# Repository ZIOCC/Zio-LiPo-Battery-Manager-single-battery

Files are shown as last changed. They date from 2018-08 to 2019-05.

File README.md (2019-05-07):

# Zio LiPo Battery Manager (Single battery)

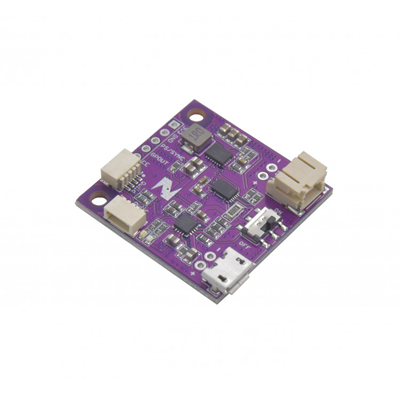
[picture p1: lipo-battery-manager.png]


> This product can be available for purchase [here](https://www.smart-prototyping.com/Zio-LiPo-Battery-Manager.html).

#### Description

This board combines a lithium polymer battery charger, fuel gauge, and voltage regulator, all in one neat little PCB. It also features a miniature DPDT power switch so that you can easily turn your project on and off without disconnecting the battery.

The Battery Manager’s TI BQ27441-G1A I2C Fuel Gauge is a Coulomb-counter, tracking the amount of power that has been discharged since your battery was fully charged. The amount of power remaining is calculated based on the capacity of that battery that you’ve set via the [Sparkfun BQ27441-G1 I2C library](https://learn.sparkfun.com/tutorials/battery-babysitter-hookup-guide#bq27441-arduino-library). Using the library, you can also read the raw voltage of your LiPo battery’s output. And because this is a Qwiic device, your MCU can check this information even if your battery and Battery Manager board are all the way at the other end of your daisy-chain of Qwiic modules. And if your Power Module is close to your MCU, just connect the GPOUT interrupt pin to one of your MCU’s GPIO pins to get a heads-up when the tank is running low. And because of the built-in current-sensing resistor circuit, you can even measure your project’s real-time current consumption.

The Battery Manager’s BQ24075 battery charger IC can charge your single-cell lithium-ion battery pack at up to 1.5A.

Our Battery Manager board is based on [Sparkfun’s Battery Babysitter](https://www.sparkfun.com/products/13777), and while the pin-out isn’t exactly the same, their [Hookup Guide](https://learn.sparkfun.com/tutorials/battery-babysitter-hookup-guide) is a great resource for getting started with our board as well.

Note: This board requires the use of the Qwiic (4-pin JST-SH) connector for accessing the I2C functionality of the BQ27441-G1A. If you intend to use this board in a project where your MCU doesn’t include a Qwiic connector, make sure you pick up a [Qwiic-to-breadboard cable](https://www.smart-prototyping.com/Prototyping-Modules/zio/Qwiic-to-Breadboard-Male-Header-150mm-Cable-2.54mm-10pcs), or any [Qwiic cable](https://www.smart-prototyping.com/index.php?route=product/search&search=qwiic%20cable) and a [Qwiic adapter board](https://www.smart-prototyping.com/Prototyping-Modules/zio/Zio-Qwiic-Adapter.html).

##### Features

* Protects the battery from running outside the safe operating area.
* Easy to connect to any ZIO products with one simple Qwiic cable.
* Features a dynamic power-path management which will maintain a solid output supply of 3.3V
* Contains a safety timer which will turn off the charger after 6.25 hours.

#### Specification

* Input Voltage- 6V max
* Output Voltage- 3.3V
* Output current- 1.5A max
* Qwiic connectors 3.3v and 1.5A max
* Battery Connector: PH Connector
* Battery Charger IC: BQ24075
* Power Manager IC: TPS63020DSJR
* Battery Gauge IC: BQ27441-G1
* I2C address:0x55
* Dimensions: 32.23x 33.24 mm
* Weight: 4.9g

#### Links

* [Eagle files](https://github.com/ZIOCC/Zio-LiPo-Battery-Manager-single-battery/tree/master/EAGLE)

> ###### About Zio
> Zio is a new line of open sourced, compact, and grid layout boards, fully integrated for Arduino and Qwiic ecosystem. Designed ideally for wearables, robotics, small-space limitations or other on the go projects. Check out other awesome Zio products [here](https://www.smart-prototyping.com/Zio).

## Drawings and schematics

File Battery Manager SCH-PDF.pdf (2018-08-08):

# GND 10k 1%

A

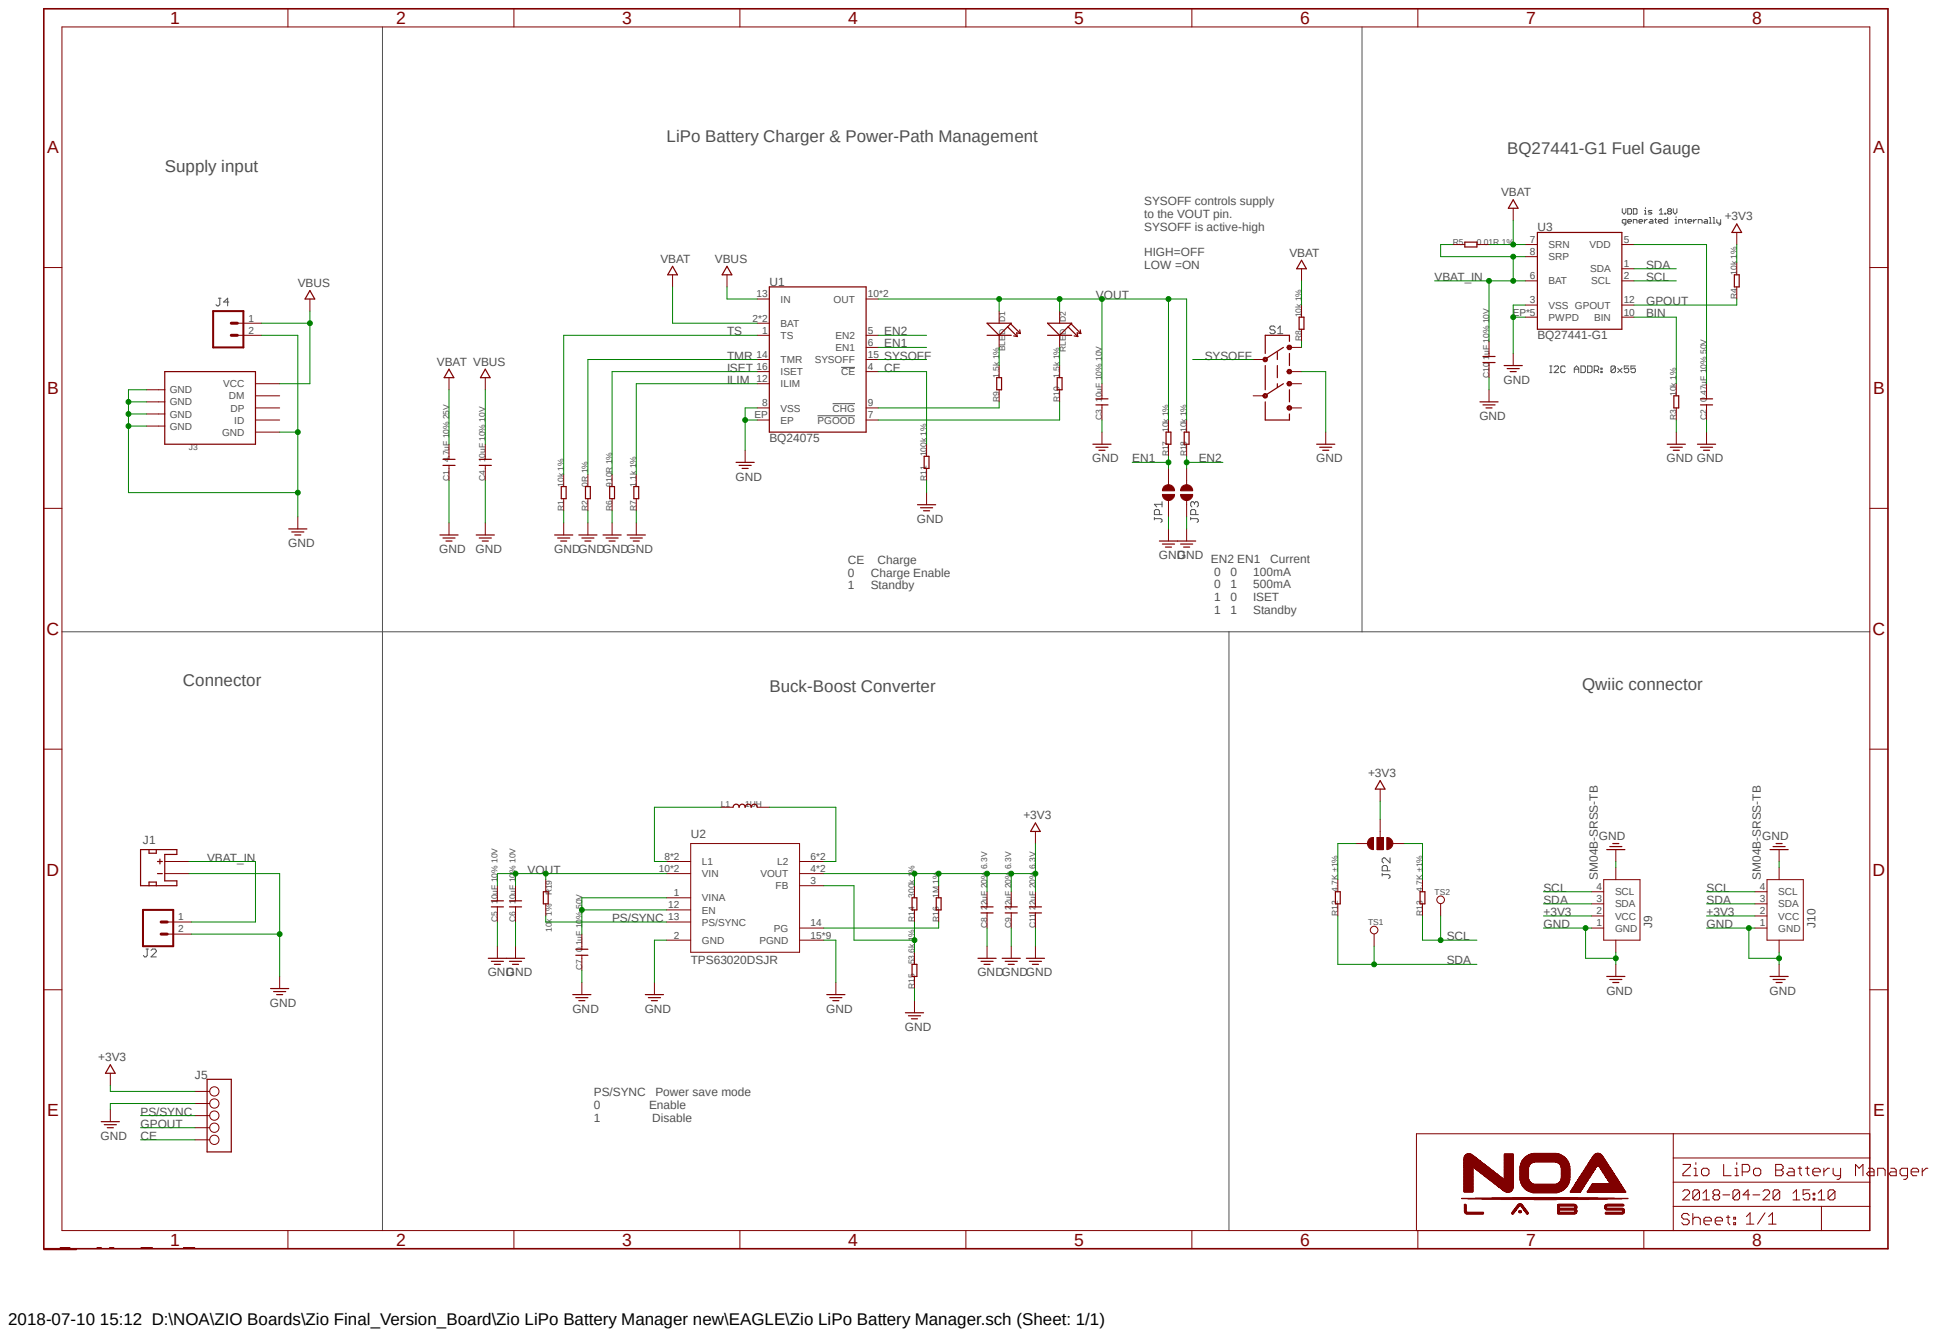
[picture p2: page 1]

Supply input | SYSOFF controls supply SYSOFF is active-high HIGH=OFF VBAT VBAT VBUS LOW =ON | BQ27441-G1 Fuel Gauge LiPo Battery Charger & Power-Path Management VBAT

to the VOUT pin.

VCC GND GND GND GND

PS/SYNC Power save mode
0 Enable
1 Disable

2018-07-10 15:12 D:\NOA\ZIO Boards\Zio Final_Version_Board\Zio LiPo Battery Manager new\EAGLE\Zio LiPo Battery Manager.sch (Sheet: 1/1)

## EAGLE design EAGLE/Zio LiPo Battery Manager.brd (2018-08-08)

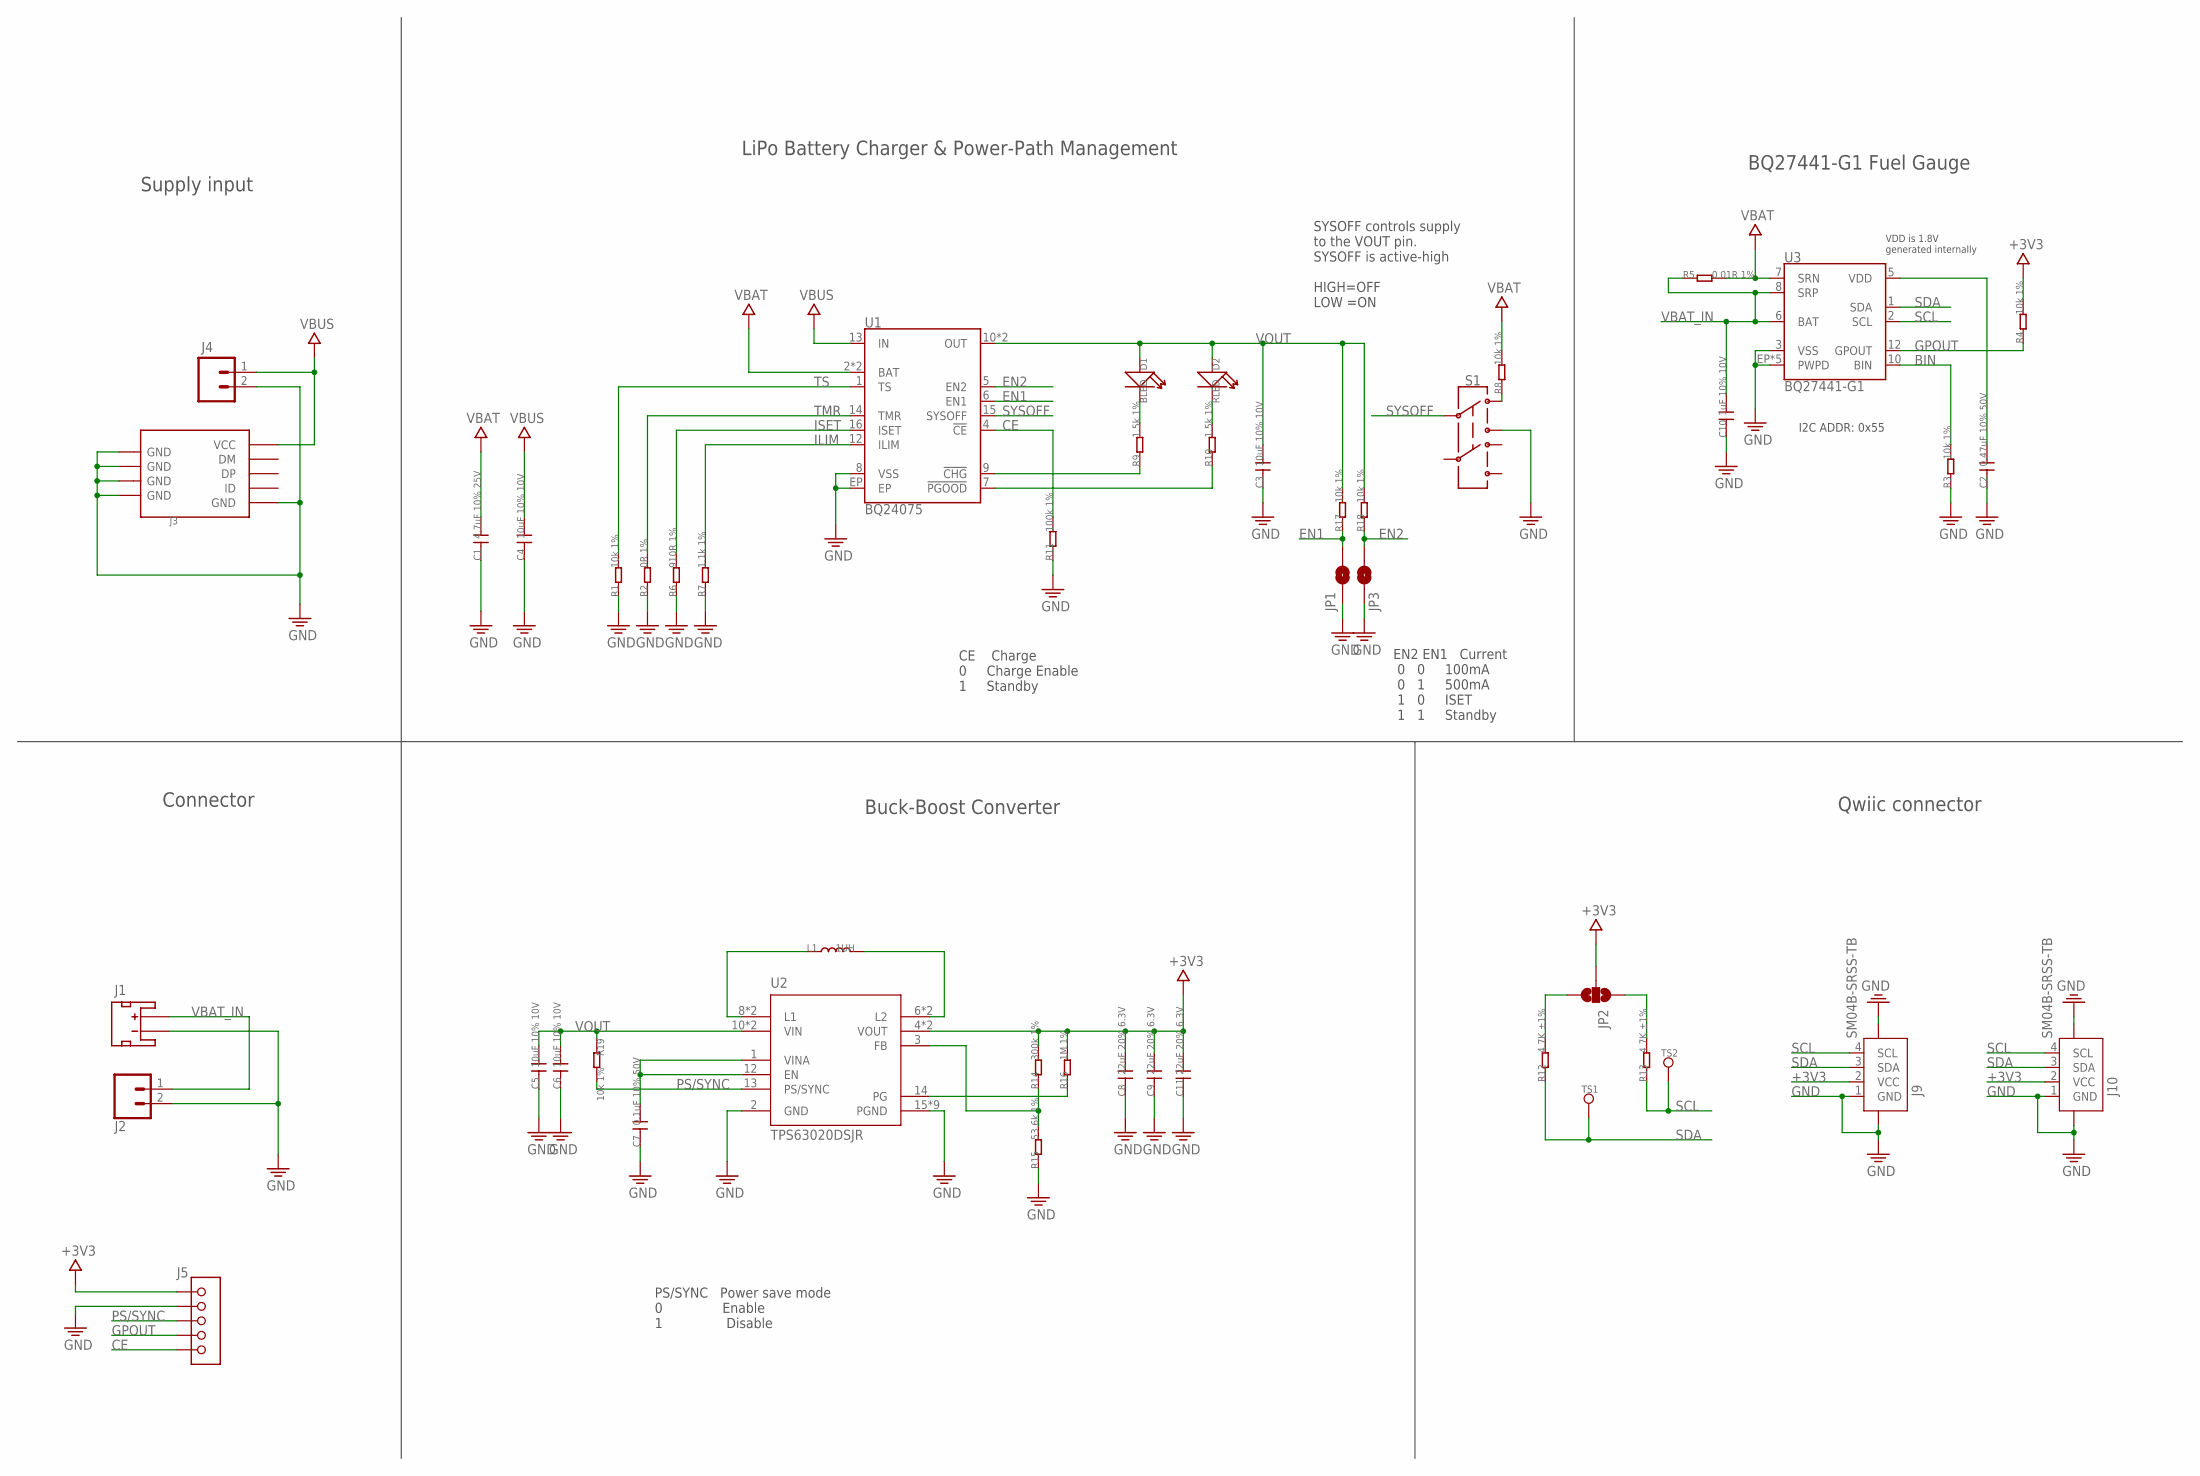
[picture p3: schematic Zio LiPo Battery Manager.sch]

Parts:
C1: 4.7uF 10% 25V; 0603
C2: 0.47uF 10% 50V; 0603
C3, C4, C5, C6: 10uF 10% 10V; 0805
C7: 0.1uF 10% 50V; 0603
C8, C9, C11: 22uF 20% 6.3V; 0805
C10: 1uF 10% 10V; 0603
D1: BLED; LED-0603
D2: RLED; LED-0603
J1: JST_2MM_MALE; JST-2-SMD
J2, J4: CONN_02; 1X02
J3: USB-MICROE; MICRO-SMD
J5: HEADER-5P-2.54; 5P-2.54
J9, J10: SM04B-SRSS-TB; JST-SH-4P
JP1, JP3: JUMPER-SMT_2_NC_PASTE_NOCREM; SMT-JUMPER_2_NC_PASTE_SILK_NOCREM
JP2: JUMPER-SMT_3_2-NC_PASTE_NOCREM; SMT-JUMPER_3_2-NC_PASTE_SILK_NOCREM
L1: 1UH; 0420M
R1, R3, R4, R8, R17, R18, R19: 10k 1%; 0603
R2: 0R 1%; 0603
R5: 0.01R 1%; 1206
R6: 910R 1%; 0603
R7: 1.1k 1%; 0603
R9, R10: 1.5k 1%; 0603
R11: 100k 1%; 0603
R12, R13: 4.7K ±1%; 0603
R14: 300k 1%; 0603
R15: 53.6k 1%; 0603
R16: 1M 1%; 0603
S1: SWITCH-DPDT-SMD-AYZ0202; SWITCH_DPDT_SMD_AYZ0202
TS1, TS2: TEST_POINT35MIL; 1P-35MIL
U1: BQ24075; PVQFN-N16
U2: TPS63020DSJR; VSON-14
U3: BQ27441-G1; PDSO-N12

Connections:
1.8V: C2.2, U3.5 (VDD)
+3V3: C8.2, C9.2, C11.2, J5.1, J9.2 (VCC), J10.2 (VCC), JP2.2, R4.2, R14.2, R16.2, U2.4 (VOUT), U2.5 (VOUT)
BIN: R3.2, U3.10 (BIN)
CE: J5.5, R11.2, U1.4 (!CE!)
EN1: JP1.2, R17.1, U1.6 (EN1)
EN2: JP3.2, R18.1, U1.5 (EN2)
GND: C1.1, C2.1, C3.1, C4.1, C5.1, C6.1, C7.1, C8.1, C9.1, C10.1, C11.1, J1.1 (-), J2.2, J3.GND, J3.S1 (GND), J3.S1@1 (GND), J3.S1@2 (GND), J3.S2 (GND), J3.S2@1 (GND), J3.S2@2 (GND), J3.S3 (GND), J3.S3@1 (GND), J3.S3@2 (GND), J3.S4 (GND), J3.S4@1 (GND), J3.S4@2 (GND), J4.2, J5.2, J9.1 (GND), J9.NC1 (5), J9.NC2 (6), J10.1 (GND), J10.NC1 (5), J10.NC2 (6), JP1.1, JP3.1, R1.1, R2.1, R3.1, R6.1, R7.1, R11.1, R15.1, S1.3, U1.8 (VSS), U1.EP, U2.2 (GND), U2.15 (PGND), U2.16 (PGND), U2.17 (PGND), U2.18 (PGND), U2.19 (PGND), U2.20 (PGND), U2.21 (PGND), U2.22 (PGND), U2.23 (PGND), U3.3 (VSS), U3.EP (PWPD), U3.EP1 (PWPD), U3.EP2 (PWPD), U3.EP3 (PWPD), U3.EP4 (PWPD)
GPOUT: J5.4, R4.1, U3.12 (GPOUT)
ILIM: R7.2, U1.12 (ILIM)
ISET: R6.2, U1.16 (ISET)
unnamed: JP2.3, R12.2
unnamed: C7.2, U2.1 (VINA), U2.12 (EN)
unnamed: R8.1, S1.1
unnamed: R9.1, U1.9 (!CHG!)
unnamed: R14.1, R15.2, U2.3 (FB)
unnamed: D1.-, R9.2
unnamed: JP2.1, R13.2
unnamed: R10.1, U1.7 (!PGOOD!)
unnamed: D2.-, R10.2
unnamed: L1.1, U2.8 (L1), U2.9 (L1)
unnamed: L1.2, U2.6 (L2), U2.7 (L2)
PG: R16.1, U2.14 (PG)
PS/SYNC: J5.3, R19.2, U2.13 (PS/SYNC)
SCL: J9.4 (SCL), J10.4 (SCL), R13.1, TS2.P$1, U3.2 (SCL)
SDA: J9.3 (SDA), J10.3 (SDA), R12.1, TS1.P$1, U3.1 (SDA)
SYSOFF: S1.2, U1.15 (SYSOFF)
TMR: R2.2, U1.14 (TMR)
TS: R1.2, U1.1 (TS)
VBAT: C1.2, R5.2, R8.2, U1.2 (BAT), U1.3 (BAT), U3.7 (SRN)
VBAT_IN: C10.2, J1.2 (+), J2.1, R5.1, U3.6 (BAT), U3.8 (SRP)
VBUS: C4.2, J3.VBUS (VCC), J4.1, U1.13 (IN)
VOUT: C3.2, C5.2, C6.2, D1.+, D2.+, R17.2, R18.2, R19.1, U1.10 (OUT), U1.11 (OUT), U2.10 (VIN), U2.11 (VIN)

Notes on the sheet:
BQ27441-G1 Fuel Gauge
LiPo Battery Charger & Power-Path Management
Qwiic connector
VDD is 1.8V generated internally
I2C ADDR: 0x55
SYSOFF controls supply to the VOUT pin. SYSOFF is active-high HIGH=OFF LOW =ON
Supply input
Buck-Boost Converter
Connector
EN2 EN1 Current 0 0 100mA 0 1 500mA 1 0 ISET 1 1 Standby
PS/SYNC Power save mode 0 Enable 1 Disable
CE Charge 0 Charge Enable 1 Standby

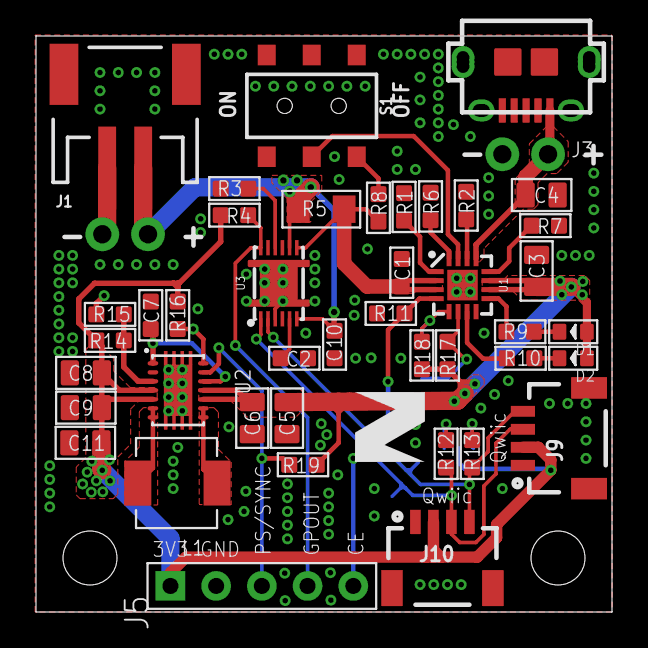
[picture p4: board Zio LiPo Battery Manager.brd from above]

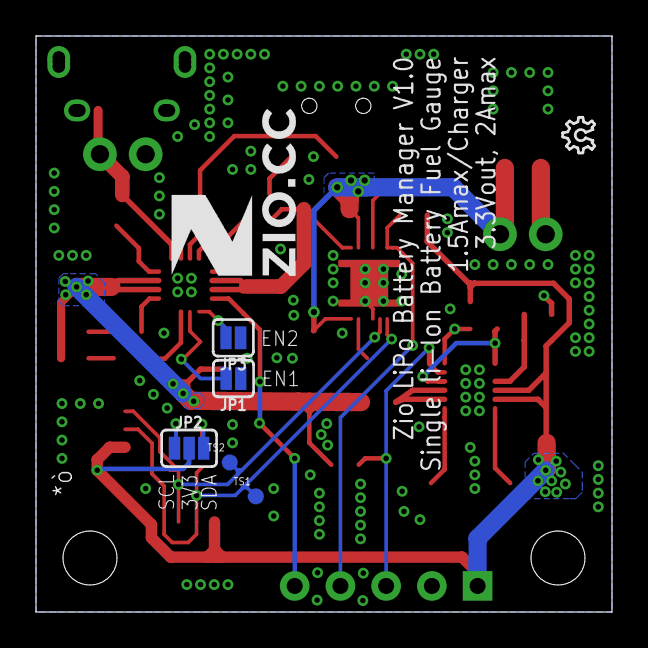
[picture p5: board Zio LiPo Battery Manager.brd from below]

Board: 2 copper layers, 32.0 x 32.0 mm, 52 parts (7 on the bottom side), 32 nets.

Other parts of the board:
LOGO1: LOGO-OSHW-6MILX0070-NT; OSHW_6X70_NOTEXT
U$1: 7MM
U$2: 6MM

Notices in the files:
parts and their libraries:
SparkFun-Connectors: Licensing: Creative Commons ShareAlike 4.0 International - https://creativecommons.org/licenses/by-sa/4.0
